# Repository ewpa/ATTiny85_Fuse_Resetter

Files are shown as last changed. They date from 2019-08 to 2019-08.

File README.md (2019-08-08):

# ATTiny85_Fuse_Resetter
Want to use all SIX GPIO pins on the ATTiny85?  Now you can.  See Ralph's video
#87 at https://www.youtube.com/c/RalphBacon

So you like the ATTiny85 chip but wish you could use *all* the pins as GPIO
pins?  Your wish is granted!

OK, you have to build (or buy) a fuse resetter but it's a small project that
just about anyone with a soldering iron can successfully complete (Benny built
mine and he's got no thumbs, remember).

If you really don't want to build one for a few dollars you can always buy one
ready made, but at least by watching this video you will understand what it is
doing.

There are some "gotchas" to watch out for (just one or two but definitely worth
knowing about) but when it comes down to it *yes* you *can* have all **six
GPIO** pins working on a Tiny85, as I prove in this video.

I wish I had known this a few years ago as I would now be using my ATTiny85
instead of a Nano to control my fridge door alarm, that's for sure.  Sometimes
a Tiny85 is all you need.  And it can run off batteries for weeks if not months,
as my previous video on the Tiny85 mentioned.

# LINKS LINKS LINKS and MORE LINKS!

High Voltage programming/Unbricking for Attiny - Yikes! Invalid device signature
https://arduinodiy.wordpress.com/2015/05/16/high-voltage-programmingunbricking-for-attiny/

ATTiny85 Spec Sheet (Good Bedtime Reading, really!)
Page 184-185 has graphs showing the current/voltage.
http://www.atmel.com/images/atmel-2586-avr-8-bit-microcontroller-attiny25-attiny45-attiny85_datasheet.pdf

Embedded Fuse Calculator (for all ATMEL chips)
http://www.engbedded.com/fusecalc/

All about ATMEGA328P (Uno/Nano) Fuse Settings
http://www.martyncurrey.com/arduino-atmega-328p-fuse-settings/

Setting and reading AtTiny85 fuses
https://dntruong.wordpress.com/2015/07/08/setting-and-reading-attiny85-fuses/

You can use `avrdude` (that's the AVR DownandUploadDEr - contrived or what?) to
give you info on fuses too.
Execute these commands:

```avrdude -F -c usbasp -p t85 -U hfuse:r:-:h```
You can remove the `-F` that just skips an invalid signature (like if you have
the RESET pin configured as an IO pin!)

# Using the Programmer

When the device is first switched on the indicator will flash a specific number
of times to denote the current state of the fuses in line with the programming
options available.  For instance, once if the fuse values are non-default but
the RST pin acts as *reset*; twice if the fuse values are non-default and the
RST pin is fused to act as a *GPIO*, and three times if the fuses are at the
factory default values.

Here is an example of the programming in action, with the output captured from
the serial console.  In this example the programming button was held down
continually for three seconds to reset the fuse values from their current
Digispark settings back to the default.

```
Turn on the 12 volt power

Entering programming Mode

Reading signature...1E930B
Reading locks and fuses
hfuse...DD
lfuse...E1
efuse...FE
lock....FF

You can ENABLE the RST pin (as RST) to allow programming
or DISABLE it to turn it into a (weak) GPIO pin.

Press the desired number or hold the button for the desired number of seconds.

1 second  : ENABLE the RST pin (back to normal)
2 seconds : DISABLE the RST pin (make it a GPIO pin)
3 seconds : Revert to factory defaults
1...2...3...

hfuse current=DD target=DF updating...done
lfuse current=E1 target=62 updating...done
efuse current=FE target=FE
lock  current=FF target=FF

Reading locks and fuses
hfuse...DF
lfuse...62
efuse...FE
lock....FF

Programming complete. Press RESET to run again.
```

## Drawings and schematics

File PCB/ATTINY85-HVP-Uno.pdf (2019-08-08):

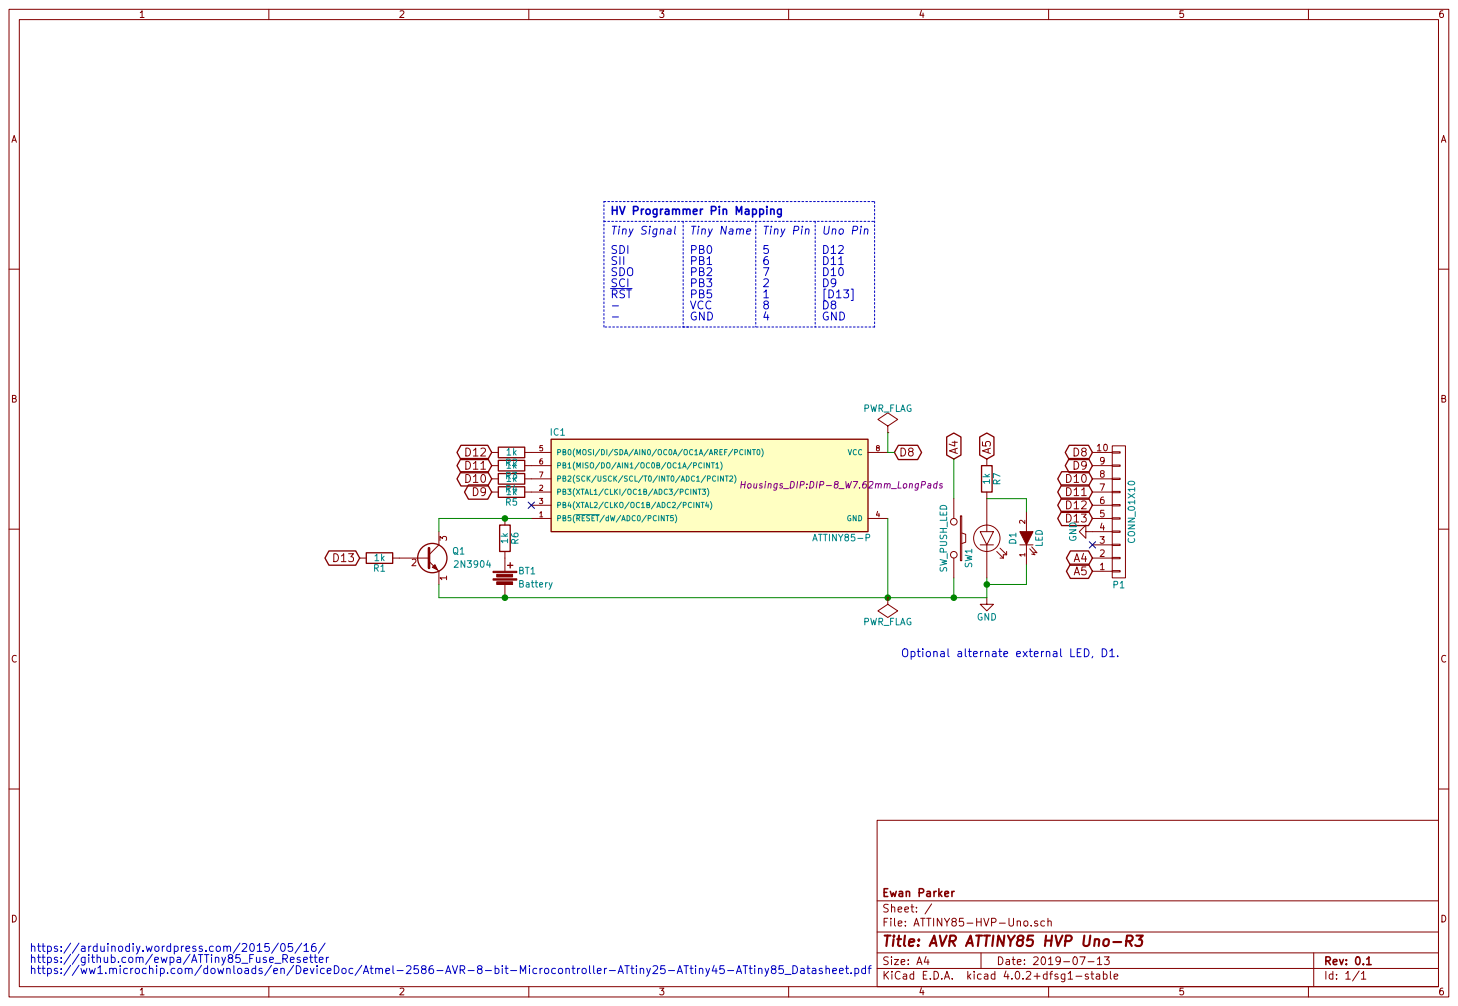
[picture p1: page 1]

Optional alternate external LED, D1.

File: ATTINY85-HVP-Uno.sch Sheet: / Ewan Parker

Id: 1/1 Title: AVR ATTINY85 HVP Uno-R3

https://arduinodiy.wordpress.com/2015/05/16/
https://github.com/ewpa/ATTiny85_Fuse_Resetter

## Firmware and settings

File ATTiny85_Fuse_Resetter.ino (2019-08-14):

#include "Arduino.h"
// AVR High-voltage Serial Programmer
// Originally created by Paul Willoughby 03/20/2010
// www.rickety.us slash 2010/03/arduino-avr-high-voltage-serial-programmer/
// Inspired by Jeff Keyzer mightyohm.com
// Serial Programming routines from ATtiny25/45/85 datasheet
// Hardware interface by Ewan Parker

// Device signatures that are understood
#define SIG_ATTINY25 0x1E9108
#define SIG_ATTINY45 0x1E9206
#define SIG_ATTINY85 0x1E930B

// The fuse types we recognize
typedef enum fuseType
{
  FUSE_T_HFUSE,        // High fuse bits
  FUSE_T_LFUSE,        // Low fuse bits
  FUSE_T_EFUSE,        // Extended fuse bits
  FUSE_T_LOCK,         // Lock bits
  FUSE_T_SIZEOF
};

// The three states we allow fuses to be set, and their option numbers
typedef enum fuseState
{
  FUSE_S_RESET_EN = 1, // Pin 1 as RESET, otherwise unchanged
  FUSE_S_RESET_GPIO,   // Pin 1 as GPIO, otherwise unchanged
  FUSE_S_DEFAULT,      // All fuses as factory default
  FUSE_S_END
};

#define  RST     13    // Output to level shifter for !RESET from NPN to Pin 1
#define  CLKOUT   9    // Connect to Serial Clock Input (SCI) Pin 2
#define  DATAIN  10    // Connect to Serial Data Output (SDO) Pin 7
#define  INSTOUT 11    // Connect to Serial Instruction Input (SII) Pin 6
#define  DATAOUT 12    // Connect to Serial Data Input (SDI) Pin 5
#define  VCC      8    // Connect to VCC Pin 8

#define  ALERT   A5    // Indicator pin
#define  PROG    A4    // Programming button input pin

// Fuse configurations
#define FUSE_MASK_RSTDISBL 0x80
// Defaults for ATtiny25/45/85
uint8_t defaultFuses[FUSE_T_SIZEOF] = { 0xDF, 0x62, 0xFF, 0xFF };
//// Defaults for Digispark ATtiny85
//uint8_t defaultFuses[FUSE_T_SIZEOF] = { 0xDD, 0xE1, 0xFE, 0xFF };
uint8_t actualFuses[FUSE_T_SIZEOF], targetFuses[FUSE_T_SIZEOF];

// Timeouts
#define TIMEOUT_RESPONSE_MS 1000

void setup()
{
  // Initialize output pins as needed
  digitalWrite(RST, HIGH);  // Level shifter is inverting, this shuts off 12V
  digitalWrite(ALERT, HIGH);

  // Set up control lines for HV programming
  pinMode(VCC, OUTPUT);
  pinMode(RST, OUTPUT);
  pinMode(DATAOUT, OUTPUT);
  pinMode(INSTOUT, OUTPUT);
  pinMode(CLKOUT, OUTPUT);
  pinMode(DATAIN, OUTPUT);  // configured as input later when programming

  // Programming pin
  pinMode(PROG, INPUT_PULLUP);

  // Buzzer / beeper / LED
  pinMode(ALERT, OUTPUT);
  delay(500);
  digitalWrite(ALERT, LOW);
  delay(1000);

  // start serial port at 9600 bps:
  Serial.begin(9600);
}

void loop()
{
  Serial.println("Turn on the 12 volt power\n");
  Serial.println("Entering programming Mode\n");

  // Initialize pins to enter programming mode
  pinMode(DATAIN, OUTPUT);  //Temporary
  digitalWrite(DATAOUT, LOW);
  digitalWrite(INSTOUT, LOW);
  digitalWrite(DATAIN, LOW);
  digitalWrite(RST, HIGH);  // Level shifter is inverting, so shuts off 12V

  // Enter High-voltage Serial programming mode
  digitalWrite(VCC, HIGH);  // Apply VCC to start programming process
  delayMicroseconds(20);
  digitalWrite(RST, LOW);   //Turn on 12v
  delayMicroseconds(10);
  pinMode(DATAIN, INPUT);   //Release DATAIN
  delayMicroseconds(300);

  //Programming mode
  uint32_t signature = readSignature();
  if (signature != SIG_ATTINY85 && signature != SIG_ATTINY45
  && signature != SIG_ATTINY25)
  {
    fatalError("Unknown device signature");
  }

  readFuses(actualFuses);   // Read the fuses and populate array
  delay(500);
  digitalWrite(ALERT, HIGH);

  switch (establishContact())
  {
    case FUSE_S_RESET_EN :
      for (uint8_t f = 0; f < FUSE_T_SIZEOF; f++)
        targetFuses[f] = actualFuses[f];
      targetFuses[FUSE_T_HFUSE] |= FUSE_MASK_RSTDISBL;
      break;
    case FUSE_S_RESET_GPIO :
      for (uint8_t f = 0; f < FUSE_T_SIZEOF; f++)
        targetFuses[f] = actualFuses[f];
      targetFuses[FUSE_T_HFUSE]
        = targetFuses[FUSE_T_HFUSE] & ~FUSE_MASK_RSTDISBL;
      break;
    case FUSE_S_DEFAULT :
      for (uint8_t f = 0; f < FUSE_T_SIZEOF; f++)
        targetFuses[f] = defaultFuses[f];
      break;
    default:
      for (uint8_t f = 0; f < FUSE_T_SIZEOF; f++)
        targetFuses[f] = actualFuses[f];
  }

  Serial.println("");

  //Write fuse if not already the value we want

  Serial.print("hfuse current=");
  Serial.print(actualFuses[FUSE_T_HFUSE], HEX);
  Serial.print(" target=");
  Serial.print(targetFuses[FUSE_T_HFUSE], HEX);
  if (actualFuses[FUSE_T_HFUSE] != targetFuses[FUSE_T_HFUSE])
  {
    Serial.print(" updating...");
    shiftOut(MSBFIRST, 0x40, 0x4C);
    shiftOut(MSBFIRST, targetFuses[FUSE_T_HFUSE], 0x2C);
    shiftOut(MSBFIRST, 0x00, 0x74);
    shiftOut(MSBFIRST, 0x00, 0x7C);
    Serial.println("done");
  }
  else
  {
    Serial.println("");
  }

  Serial.print("lfuse current=");
  Serial.print(actualFuses[FUSE_T_LFUSE], HEX);
  Serial.print(" target=");
  Serial.print(targetFuses[FUSE_T_LFUSE], HEX);
  if (actualFuses[FUSE_T_LFUSE] != targetFuses[FUSE_T_LFUSE])
  {
    //Write lfuse
    Serial.print(" updating...");
    shiftOut(MSBFIRST, 0x40, 0x4C);
    shiftOut(MSBFIRST, targetFuses[FUSE_T_LFUSE], 0x2C);
    shiftOut(MSBFIRST, 0x00, 0x64);
    shiftOut(MSBFIRST, 0x00, 0x6C);
    Serial.println("done");
  }
  else
  {
    Serial.println("");
  }

  Serial.print("efuse current=");
  Serial.print(actualFuses[FUSE_T_EFUSE], HEX);
  Serial.print(" target=");
  Serial.print(targetFuses[FUSE_T_EFUSE], HEX);
  if (actualFuses[FUSE_T_EFUSE] != targetFuses[FUSE_T_EFUSE])
  {
    //Write efuse
    Serial.print(" updating...");
    shiftOut(MSBFIRST, 0x40, 0x4C);
    shiftOut(MSBFIRST, 0xFF, 0x2C);
    shiftOut(MSBFIRST, 0x00, 0x66);
    shiftOut(MSBFIRST, 0x00, 0x6E);
    Serial.println("done");
  }
  else
  {
    Serial.println("");
  }

  Serial.print("lock  current=");
  Serial.print(actualFuses[FUSE_T_LOCK], HEX);
  Serial.print(" target=");
  Serial.print(targetFuses[FUSE_T_LOCK], HEX);
  if (actualFuses[FUSE_T_LOCK] != targetFuses[FUSE_T_LOCK])
  {
    //Write lock
    Serial.print(" updating...");
    shiftOut(MSBFIRST, 0x20, 0x4C);
    shiftOut(MSBFIRST, 0xFF, 0x2C);
    shiftOut(MSBFIRST, 0x00, 0x64);
    shiftOut(MSBFIRST, 0x00, 0x6C);
    Serial.println("done");
  }
  else
  {
    Serial.println("");
  }

  // Confirm new state of play
  Serial.println("");
  delay(1000);
  readFuses(actualFuses);
  digitalWrite(ALERT, LOW);

  digitalWrite(CLKOUT, LOW);
  digitalWrite(VCC, LOW);
  digitalWrite(RST, HIGH);   //Turn off 12v

  Serial.println("Programming complete. Press RESET to run again.");
  while (true) {}
}

char establishContact()
{
  Serial.println("You can ENABLE the RST pin (as RST) to allow programming");
  Serial.println("or DISABLE it to turn it into a (weak) GPIO pin.\n");
  Serial.println("Press the desired number or hold the button for the desired "
                 "number of seconds.");

  // We must get a valid choice to proceed
  unsigned char reply;

  do
  {
    digitalWrite(ALERT, HIGH);
    Serial.println();
    Serial.println("1 second  : ENABLE the RST pin (back to normal)");
    Serial.println("2 seconds : DISABLE the RST pin (make it a GPIO pin)");
    Serial.println("3 seconds : Revert to factory defaults");

    int buttonPressedMs = 0;
    bool buttonState, buttonReleased = false;
    while (!Serial.available() && !buttonReleased)
    {
      // Wait for user input
      delay(20);
      buttonState = !digitalRead(PROG);
      if (buttonPressedMs > 0) digitalWrite(ALERT, LOW);
      if (!buttonState && buttonPressedMs > 0)
        buttonReleased = true;
      else buttonPressedMs += buttonState * 20;
      if (buttonPressedMs%1000 == 0 && buttonPressedMs > 0)
      {
        Serial.print(buttonPressedMs/1000);
        Serial.print("...");
        digitalWrite(ALERT, HIGH);
      }
    }

    if (buttonPressedMs >= 1000)
    {
      reply = buttonPressedMs/1000;
      Serial.println();
    }
    else if (Serial.available()) reply = Serial.read() - '0';
    else reply = 0;
  }
  while (!(reply >= 1 && reply < FUSE_S_END));

  digitalWrite(ALERT, LOW);
  return reply;
}

int shiftOut(uint8_t bitOrder, byte val, byte val1)
{
  int i;
  int inBits = 0;
  //Wait until DATAIN goes high
  unsigned long m = millis();
  while (millis() - m < TIMEOUT_RESPONSE_MS && !digitalRead(DATAIN)) {}
  if (!digitalRead(DATAIN)) fatalError("Timeout waiting for ATtiny response");

  //Start bit
  digitalWrite(DATAOUT, LOW);
  digitalWrite(INSTOUT, LOW);
  digitalWrite(CLKOUT, HIGH);
  digitalWrite(CLKOUT, LOW);

  for (i = 0; i < 8; i++)
  {
    if (bitOrder == LSBFIRST)
    {
      digitalWrite(DATAOUT, !!(val & (1 << i)));
      digitalWrite(INSTOUT, !!(val1 & (1 << i)));
    }
    else
    {
      digitalWrite(DATAOUT, !!(val & (1 << (7 - i))));
      digitalWrite(INSTOUT, !!(val1 & (1 << (7 - i))));
    }
    inBits <<= 1;
    inBits |= digitalRead(DATAIN);
    digitalWrite(CLKOUT, HIGH);
    digitalWrite(CLKOUT, LOW);

  }

  //End bits
  digitalWrite(DATAOUT, LOW);
  digitalWrite(INSTOUT, LOW);
  digitalWrite(CLKOUT, HIGH);
  digitalWrite(CLKOUT, LOW);
  digitalWrite(CLKOUT, HIGH);
  digitalWrite(CLKOUT, LOW);

  return inBits;
}

// Returns the value of the device signature
uint32_t readSignature()
{
  uint32_t signature = 0x00;
  int inData = 0;        // incoming serial byte AVR
  Serial.print("Reading signature...");

  for (int b = 0; b <= 2; b++)
  {
    shiftOut(MSBFIRST, 0x08, 0x4C);
    shiftOut(MSBFIRST, b, 0x0C);
    shiftOut(MSBFIRST, 0x00, 0x68);
    inData = shiftOut(MSBFIRST, 0x00, 0x6C);
    signature = (signature << 8) + inData;
  }
  Serial.println(signature, HEX);
  return signature;
}

// Populates the values of the fuses and lock bits
void readFuses(uint8_t fuses[])
{
  int inData = 0;        // incoming serial byte AVR
  Serial.println("Reading locks and fuses");

  //Read hfuse
  Serial.print("hfuse...");
  shiftOut(MSBFIRST, 0x04, 0x4C);
  shiftOut(MSBFIRST, 0x00, 0x7A);
  inData = shiftOut(MSBFIRST, 0x00, 0x7E);
  fuses[FUSE_T_HFUSE] = (fuseType)inData;
  Serial.println(fuses[FUSE_T_HFUSE], HEX);

  //Read lfuse
  Serial.print("lfuse...");
  shiftOut(MSBFIRST, 0x04, 0x4C);
  shiftOut(MSBFIRST, 0x00, 0x68);
  inData = shiftOut(MSBFIRST, 0x00, 0x6C);
  fuses[FUSE_T_LFUSE] = (fuseType)inData;
  Serial.println(fuses[FUSE_T_LFUSE], HEX);

  //Read efuse
  Serial.print("efuse...");
  shiftOut(MSBFIRST, 0x04, 0x4C);
  shiftOut(MSBFIRST, 0x00, 0x6A);
  inData = shiftOut(MSBFIRST, 0x00, 0x6E);
  fuses[FUSE_T_EFUSE] = (fuseType)inData;
  Serial.println(fuses[FUSE_T_EFUSE], HEX);

  //Read lock
  Serial.print("lock....");
  shiftOut(MSBFIRST, 0x04, 0x4C);
  shiftOut(MSBFIRST, 0x00, 0x78);
  inData = shiftOut(MSBFIRST, 0x00, 0x7C);
  fuses[FUSE_T_LOCK] = (fuseType)inData;
  Serial.println(fuses[FUSE_T_LOCK], HEX);

  Serial.println();

  // Indicate the state of the fuses with the indicator LED
  fuseState s = (fuseState)0;
  bool resetEnabled = actualFuses[FUSE_T_HFUSE] & FUSE_MASK_RSTDISBL;
  if (resetEnabled)
  {
    s = FUSE_S_DEFAULT;
    for (int f = 0; f < FUSE_T_SIZEOF; f++)
    {
      if (defaultFuses[f] != actualFuses[f]) s = FUSE_S_RESET_EN;
    }
  }
  else s = FUSE_S_RESET_GPIO;

  while (s > 0)
  {
    digitalWrite(ALERT, LOW);
    delay(400);
    digitalWrite(ALERT, HIGH);
    delay(100);
    s = (fuseState)(s - 1);
  }
  digitalWrite(ALERT, LOW);
  delay(500);
}

// A fatal error from which the program never returns.
void fatalError(String msg)
{
  Serial.println();
  Serial.println("*** Fatal error ***");
  Serial.println(msg);
  Serial.println();
  Serial.println("RESET to restart");
  while (true)
  {
    digitalWrite(ALERT, !digitalRead(ALERT));
    delay(200);
  }
}

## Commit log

2019-08-07 Simplify GPIO pin naming and initialization.
2019-08-08 Allow use of hardware button as an additional input device.
2019-08-08 Make the fuse ordering consistent and update the README.
2019-08-08 Use the indicator LED to show the fuse state so no serial console required.
2019-08-08 Add the PCB files for a single layer through-hole board.
    [ATTINY85-HVP-Uno-B.Cu.gbr, ATTINY85-HVP-Uno-B.Mask.gbr, ATTINY85-HVP-Uno-F.SilkS.gbr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]
2019-08-08 Add schematic file for the associated PCB.
